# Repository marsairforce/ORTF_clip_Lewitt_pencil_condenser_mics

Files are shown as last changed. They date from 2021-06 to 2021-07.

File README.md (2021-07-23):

# An ORTF clip for Lewitt style microphones

A clip for [The ORTF stereo technique](https://en.wikipedia.org/wiki/ORTF_stereo_technique) with Lewitt style condenser microphones.

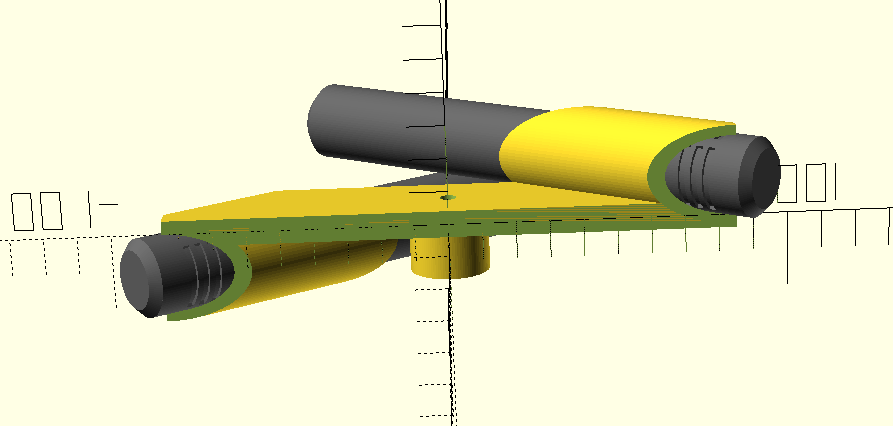
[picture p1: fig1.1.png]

The version 1.1. design.

This should work for Lewitt style 24.5 mm diameter pencil condenser microphones:

* LCT 040
* LCT 140
* LCT 340

Of course the OpenScad model is kind of parameteric, so it should be adjustable for different diameter microphones as well.

> I am not very good at OpenSCAD. I just sort of hack my way through it and learn things as I need to. I mostly use it to design 3D electronic component models for KiCAD footprints.
>
> If you have better ideas for how to improve this I am open to suggestions.

## V1.0 (June 3, 2021)

I measured the microphones I had with calipers and threw a dart to guess how thick the material should be

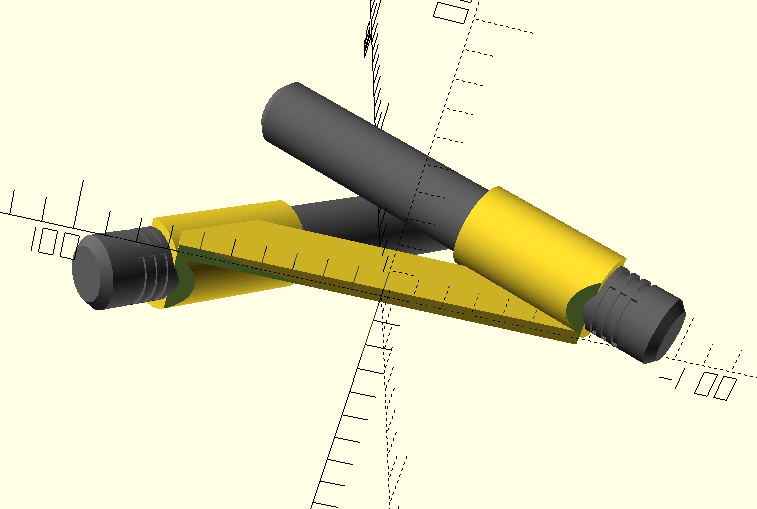
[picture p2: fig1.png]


I created this using OpenSCAD.

Here I sort of just designed a microphone model. Then made two microphones oriented in their position.
and then, I dumbly iterated editing a cylinder with a difference of the microphone body.
Then added a cube in the middle as the beam.
And then kept editing and adjusting things until it "looked ok" on the screen. Then export a STL.

> I know there are better ways to do this. I might even clean this up someday. I just wanted to prototype this for now.

I found a friend who had a 3D resin printer. And got them to build this for me!

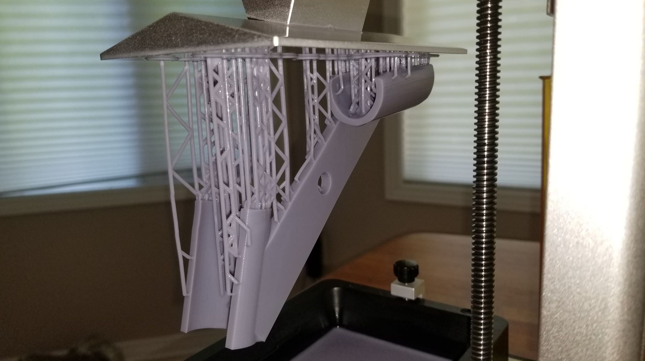
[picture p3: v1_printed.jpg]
v1_printed


This worked out unbelievably well. The model was designed with "zero tollerances" (to the size of the microphones). I was expecting there to be a little bit of variance in the inner size of the clamp if I was to FDM print this. So then having to file it, or iterate it to get the size right. But here, the size seems to grip the microphones well enough.

Feedback:

* The resin is sort of brittle and less forgiving (to dropping) than FDM print would be.
* The sharp edges are sort of hard to get nice looking. I should update the flat faces on the edge of the clip to be a bit rounded.
* I should add a fillett on the inside of the beam where it attaches to the clip part, to provide additional durability.
* Adding a round post that can be threaded with the standard wide microphone screw would be neat.

## V1.1 (June 17, 2021)

I ended up dropping the V1.0 model when attaching it to a mic stand. It shattered into several pieces.

I guess resin printing is sort of brittle like that. And that I need to make the bits a little more thicker to not be so delicate.

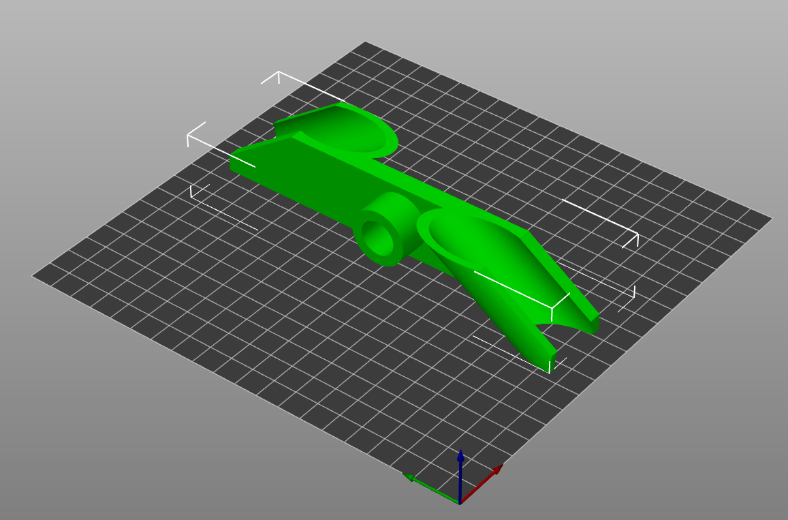
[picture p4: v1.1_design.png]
v1.1 design


This edition

* Make the beam between the clip parts thicker and taller
* Make the clip profile at the top flush with the top of the beam.
* Make the clips extend down all the way to the bottom. So it is easier to print this.
* Experiment with adding a cylinder in the middle for mounting onto a microphone stand.

(Update: July 19, 2021)

I got this design printed.

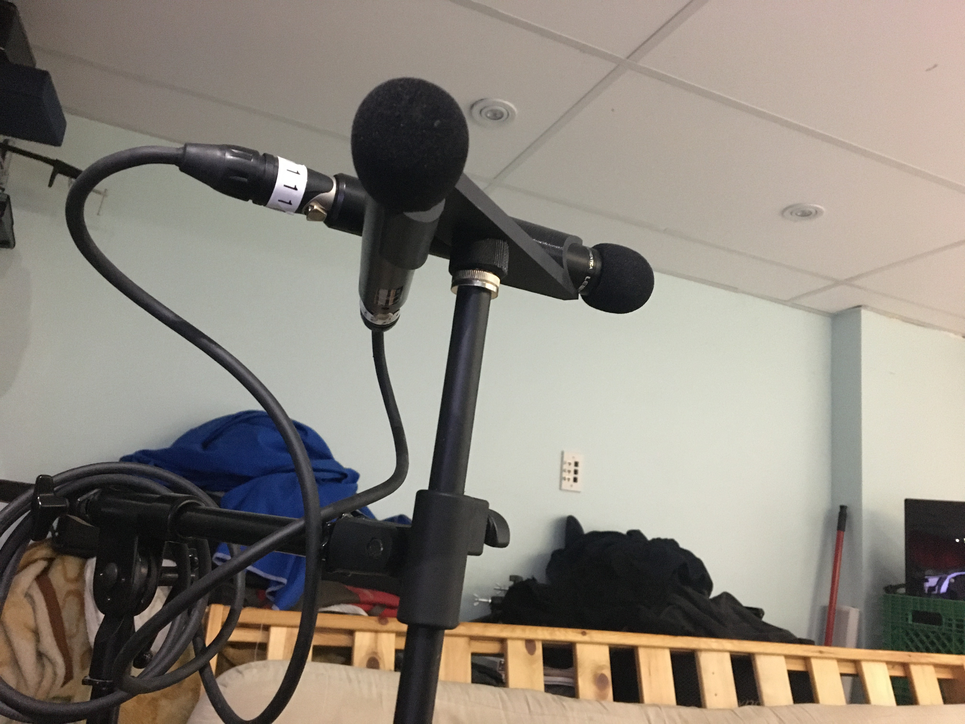
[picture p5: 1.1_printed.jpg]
v1.1_printed


It feels nice and springy, but not brittle too. Which is important, as I tend to drop things a lot.

The spot for the threads works well too.
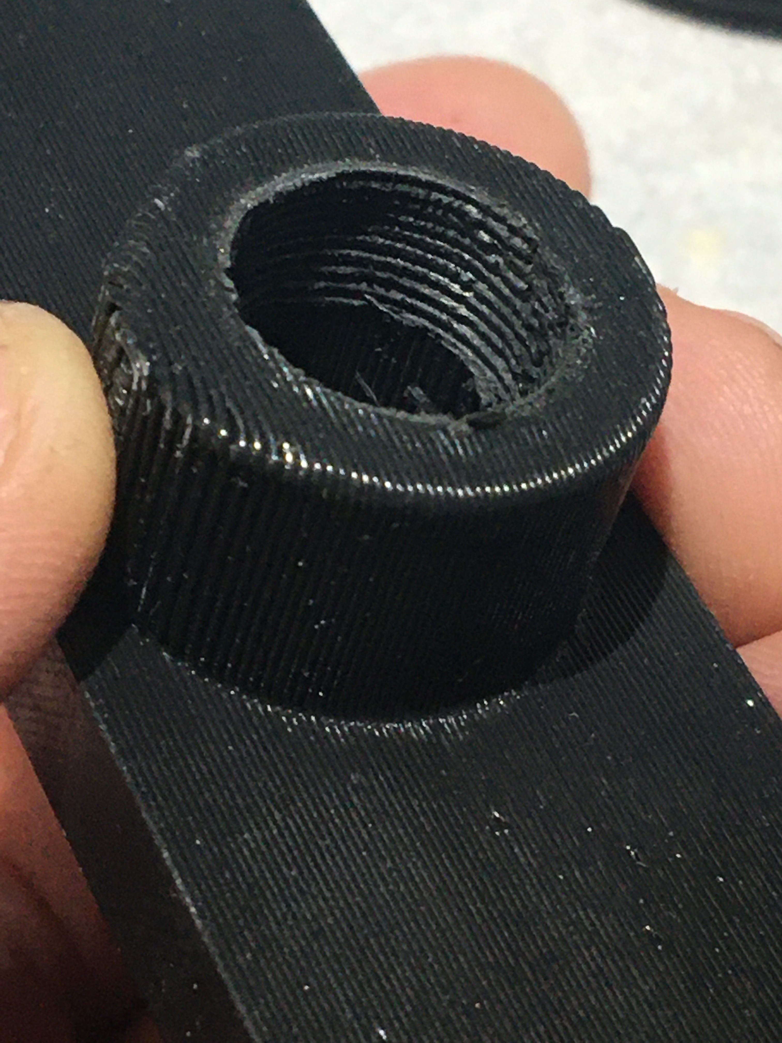
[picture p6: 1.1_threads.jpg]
1.1. threads


I used a lighter to heat up the metal end of a mic stand and then turned that into the plastic. It took a couple attempts as it kept cooling down on me. But this clip now reliably threads onto a regular microphone stand.

## License

These cad files are licensed using MIT license.

I designed these to solve my specific problem, of wanting a way to set up a pair of mics to capture a live musical performance in a room. I only have hope that this may be useful to someone else who has similar use cases.

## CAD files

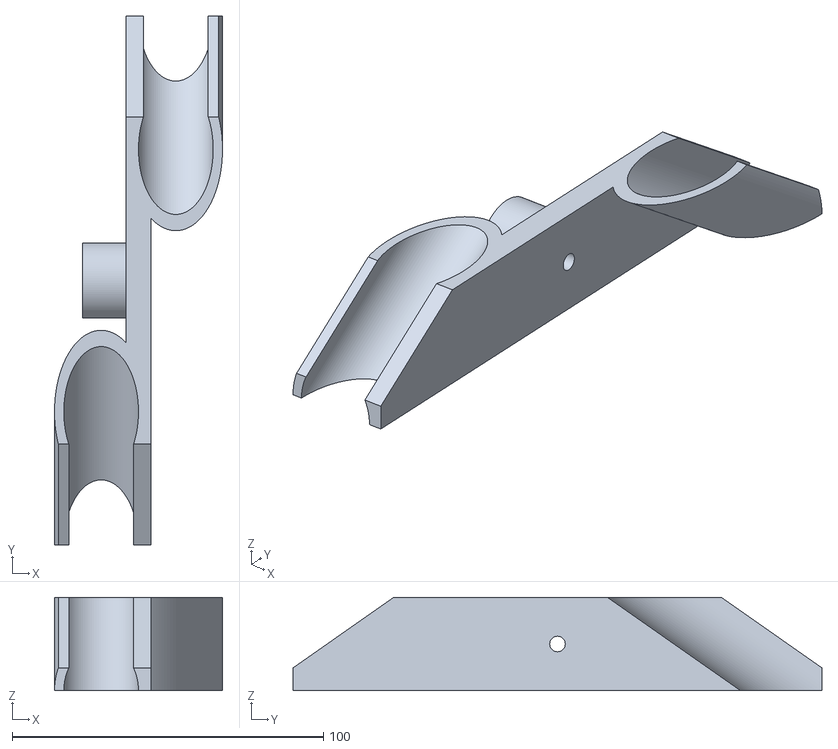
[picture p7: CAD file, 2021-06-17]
ORTF_clip_Lewitt_pencil_condenser_mics.stl
54.0 x 170.0 x 30.0

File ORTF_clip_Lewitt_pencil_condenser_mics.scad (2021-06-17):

$fn=100;


// microphone properties
mic_l=163; // total length of microphone
mic_d=24;  // the diameter of the microphone
capsule_depth=10; // how far in from the end of the 
mic_color= "#5F5F5F";
microphone_visible = false;

// ORTF spec
capsul_distance=170; // the distance between capsules
mic_angle=110;  // angle (in degrees)

// plastic printing
thick=3;    // thickness of plastic parts.
plate_thick=8;
cradle_length=90;
cradle_offset=25; // distance from tip of microphone to end of cradle start

ph=30; // height of the clip on z axis
module mic_ring() {
    difference() {
        color(mic_color)
        cylinder (h=2.2, r=mic_d/2+0.01, center=true);   
    
        color(mic_color)
        cylinder (h=2.2+0.01, r=mic_d/2-1, center=true);   
        
        rotate([0,0,-60])translate([mic_d/4,0,0])
        color(mic_color)
        cube([mic_d/2,3.5,2.2+0.01],center=true);
        
        rotate([0,0,60])translate([mic_d/4,0,0])
        color(mic_color)
        cube([mic_d/2,3.5,2.2+0.01],center=true);
        
        rotate([0,0,180])translate([mic_d/4,0,0])
        color(mic_color)
        cube([mic_d/2,3.5,2.2+0.01],center=true);
    }    
}

module mic_body() {
    
    color(mic_color)cylinder(h=mic_l-6, r = mic_d/2, center=true);
    
    translate([0,0,mic_l/2-1.5])
    color(mic_color)
    cylinder(h=3, r1 = mic_d/2, r2 = mic_d/2-3, center=true);
    
    translate([0,0,-mic_l/2+1.5])
    color(mic_color)
    cylinder(h=3, r2 = mic_d/2, r1 = mic_d/2-3, center=true);
}

module microphone() {
    difference() {
    mic_body();
        
    translate([0,0,mic_l/2 -13.8])mic_ring();
    translate([0,0,mic_l/2 -13.8 - 4])mic_ring();
    translate([0,0,mic_l/2 -13.8 - 8])mic_ring();
    }    
}

module mic_cradle() {
    translate([0,0,mic_l/2-cradle_length/2 - cradle_offset])
    rotate([0,0,90])
    {
    difference() {
        cylinder(h=cradle_length,r=mic_d/2+thick, center=true);

        cylinder(h=cradle_length+0.01,r=mic_d/2, center=true);

        translate([0,0.5*mic_d,0])
        cube([mic_d+2*thick,mic_d/2, cradle_length+0.01], center=true);
    }
    }
}

module mic_cradle_footprint() {
    translate([0,0,mic_l/2-cradle_length/2+25 - cradle_offset])
    rotate([0,0,90]){

        cylinder(h=cradle_length,r=mic_d/2+thick, center=true);
    
    translate([15,18.5,8])cube([16,25,60],center=true);
    }
}

module bridge() {
  
  pl=170;
    
  difference() {
    union() {
        translate([ph/2,0,0])cube([ph,pl,plate_thick], center=true); 
    }
   
     
    translate([0,capsul_distance/2,0]) {
            rotate([0,0,-90-mic_angle/2])
            translate([0,mic_l/2-capsule_depth,-mic_d/2])
            rotate([90,0,0]){
                union() {
                    mic_cradle_footprint();
                }
            }
 
            }
   translate([0,-capsul_distance/2,0]) {
       
            rotate([0,0,90+mic_angle/2])
            translate([0,-mic_l/2+capsule_depth,mic_d/2])
            rotate([-90,0,0]) {
                mic_cradle_footprint();
            }  
        }

  // mounting hole
  translate([ph/2,0,0])cylinder(r=2.5, h=10, center=true);
  }
  
  rm=14.87;
  
  difference() {
  translate([ph/2,0,7+plate_thick/2])cylinder(r=24
      /2, h=14, center=true);
  
  
  translate([ph/2,0,7+plate_thick/2])cylinder(r=rm/2, h=14+0.01, center=true);
  }
}

module clip(){
    rotate([0,-90,0]) {
    difference() {
        union() {
            translate([0,capsul_distance/2,0])
            rotate([0,0,-90-mic_angle/2])
            translate([0,mic_l/2-capsule_depth-23.5,-mic_d/2])
            rotate([90,0,0]){
                mic_cradle();
            }

            
            translate([0,-capsul_distance/2,0])
            rotate([0,0,90+mic_angle/2])
            translate([0,-mic_l/2+capsule_depth+23.5,mic_d/2])
            rotate([-90,0,0]) {
                mic_cradle();
            }
           
            bridge(); 
        }

    // trim edge off bottom
    translate([-9,0,0])cube([18,195,60], center=true);
        
    // trim edge off top
    bt=25;
    translate([bt/2+ph,0,0])cube([bt,140,55], center=true);
    
    // trim off bottom points of clip 
    translate([0,capsul_distance/2,0])
    translate([0,6,0])cube([20,12,60], center=true);    

    translate([0,-capsul_distance/2,0])
    translate([0,-6,0])cube([20,12,60], center=true);    

    }

}
    
}

module microphones(){
    rotate([0,-90,0])
        union() {
            translate([0,capsul_distance/2,0])
            rotate([0,0,-90-mic_angle/2])
            translate([0,mic_l/2-capsule_depth,-mic_d/2])
            rotate([90,0,0]){
                if (microphone_visible)
                    microphone();
            }

            translate([0,-capsul_distance/2,0])
            rotate([0,0,90+mic_angle/2])
            translate([0,-mic_l/2+capsule_depth,mic_d/2])
            rotate([-90,0,0]) {
                if (microphone_visible)
                    microphone();
            }
        }
}



//mic_cradle();
//bridge();
clip();
microphones();

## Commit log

2021-05-30 initial import
    [ORTF_clip_Lewitt_pencil_condenser_mics.scad, ORTF_clip_Lewitt_pencil_condenser_mics.stl]
2021-06-04 replace bridge polyhedron with cube and difference
    [ORTF_clip_Lewitt_pencil_condenser_mics.scad, ORTF_clip_Lewitt_pencil_condenser_mics.stl]
2021-06-17 Design version 1.1
    [ORTF_clip_Lewitt_pencil_condenser_mics.scad, ORTF_clip_Lewitt_pencil_condenser_mics.stl]
2021-07-23 receive printed v1.1 create media to show it off
